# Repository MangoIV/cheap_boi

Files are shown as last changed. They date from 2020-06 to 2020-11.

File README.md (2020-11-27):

# The cheap_boi mechanical keyboard
### The cheap_boi is going to be a new custom mechanical keyboard with a low pricetag
## TL;DR
- WIP, PCB v0.2 has been tested and confirmed working 
- cheap, ortholinear keyboard with  OLED-Display and RGB underglow
- Gerbers added, print on own risk
- [BOM](http://htmlpreview.github.io/?https://github.com/MangoIV/cheap_boi/bom/ibom.html)
## Render of front side
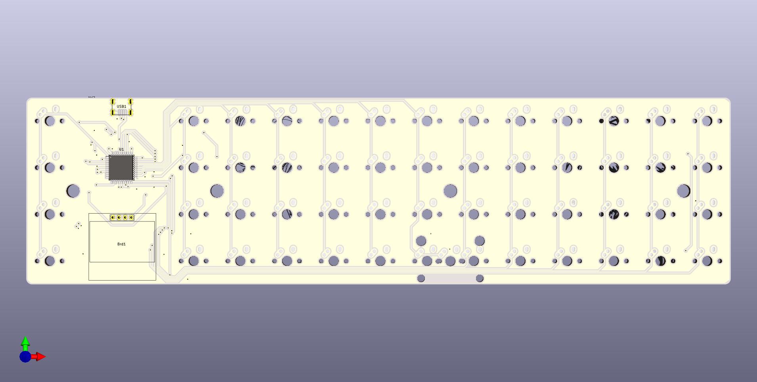
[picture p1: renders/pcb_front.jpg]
render of front side

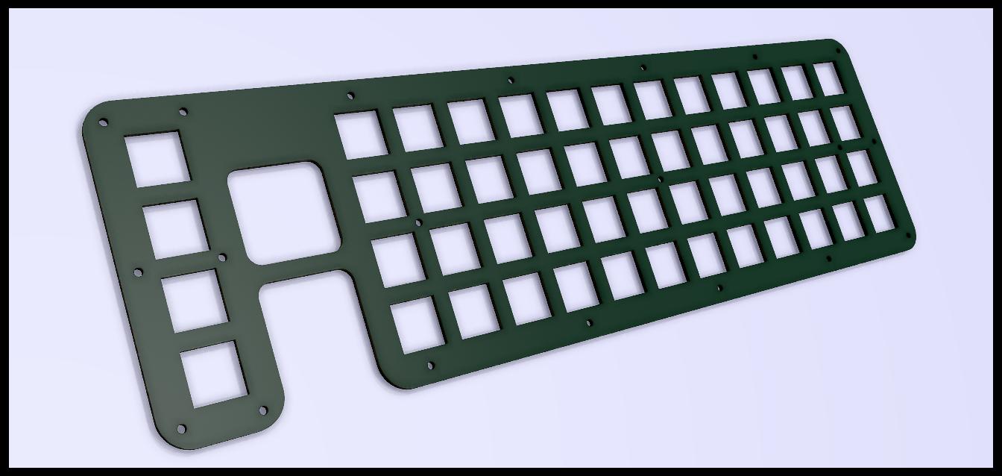
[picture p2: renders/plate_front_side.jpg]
render of front side render of the plate

## Features
### implemented
- microcontroller ATmega32u4
- ortholinear layout similar to the planck
- 4 individual function keys 
- underglow LEDs using WS2812B
- OLED display using SSD1306
- FR4 Bottom- and Switchplate with windows to see microcontroller and OLED
- have a look at the folder "renders" to see renders of the PCB and plates
- a working firmware exists on my fork of the qmk_firmware on the branch cheap_boi
- acrylic case has been made and is confirmed working 
- easier crystal footprint since v0.2
### planned
- alps/mx hybrid switch cutouts on the top plate
- add some nice silkscreen art on PCB and top plate 
### in the future
- change the design to arm, won't come that quickly though 
### current status concerning prototype
- PCBs and parts have arrived and been tested
- the second Prototype has been built and is fully working 
### problems of the current design
- the fit of the acrylic top plate wit the oled is very tight. this results in the need of filing of some materials off the corner of the oleds, this isn't much work tho and doesn't change the functionality of the oled

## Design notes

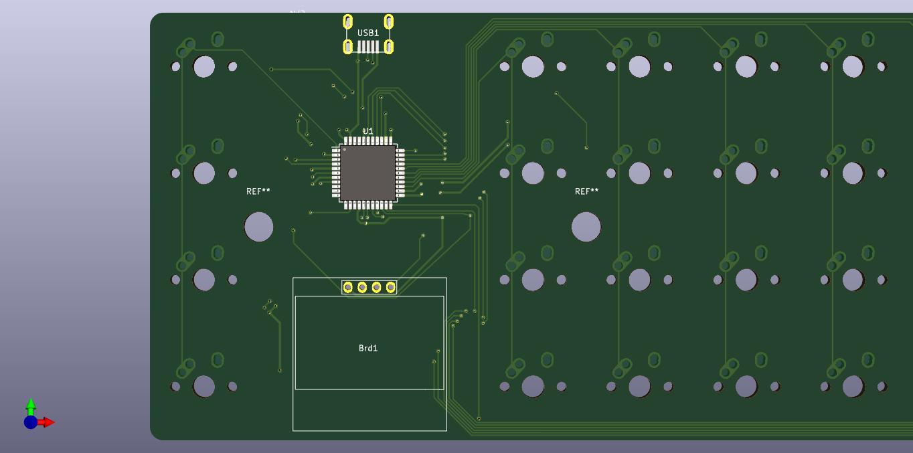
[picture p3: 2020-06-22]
renders/pcb_MCU_area.jpg

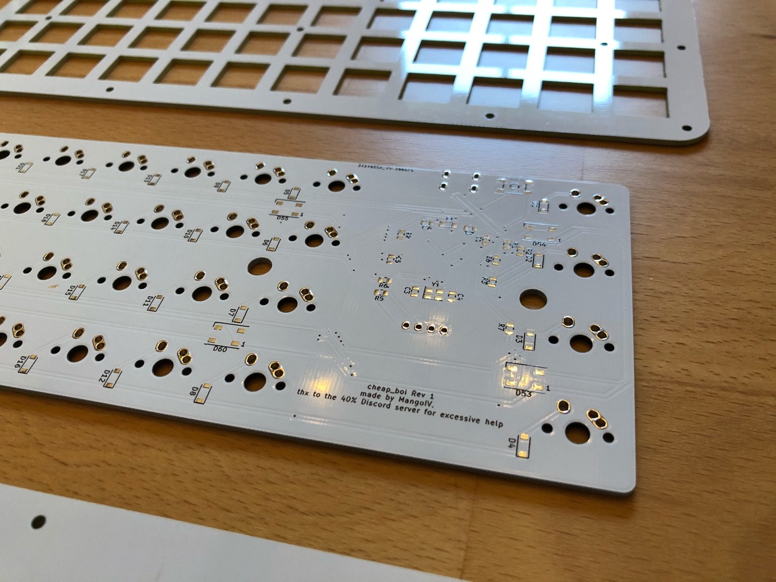
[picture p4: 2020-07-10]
pictures/pcb_back_closeup.jpeg

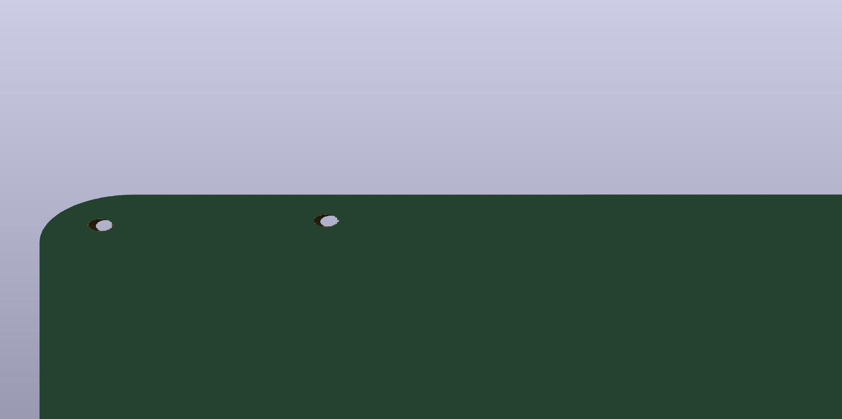
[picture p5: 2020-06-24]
renders/bottom_plate.jpg

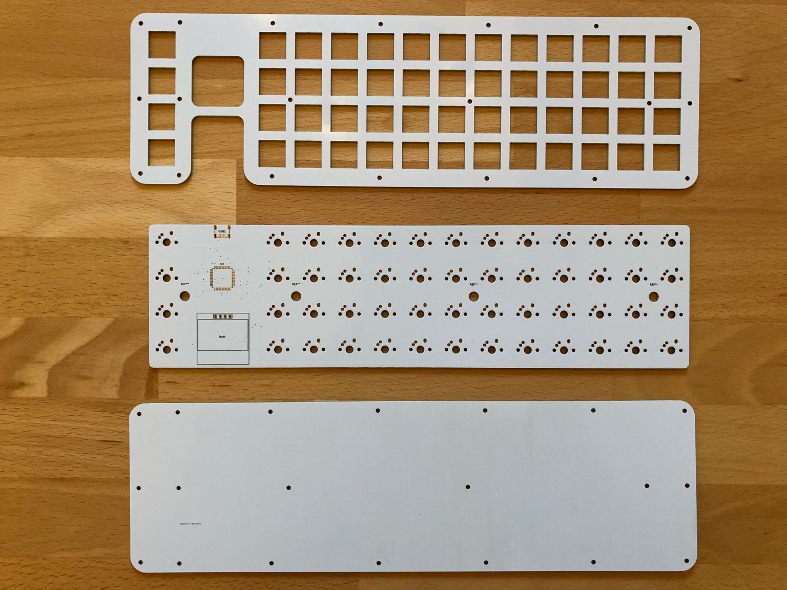
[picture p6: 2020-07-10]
pictures/plate_pcb_bottom.jpeg

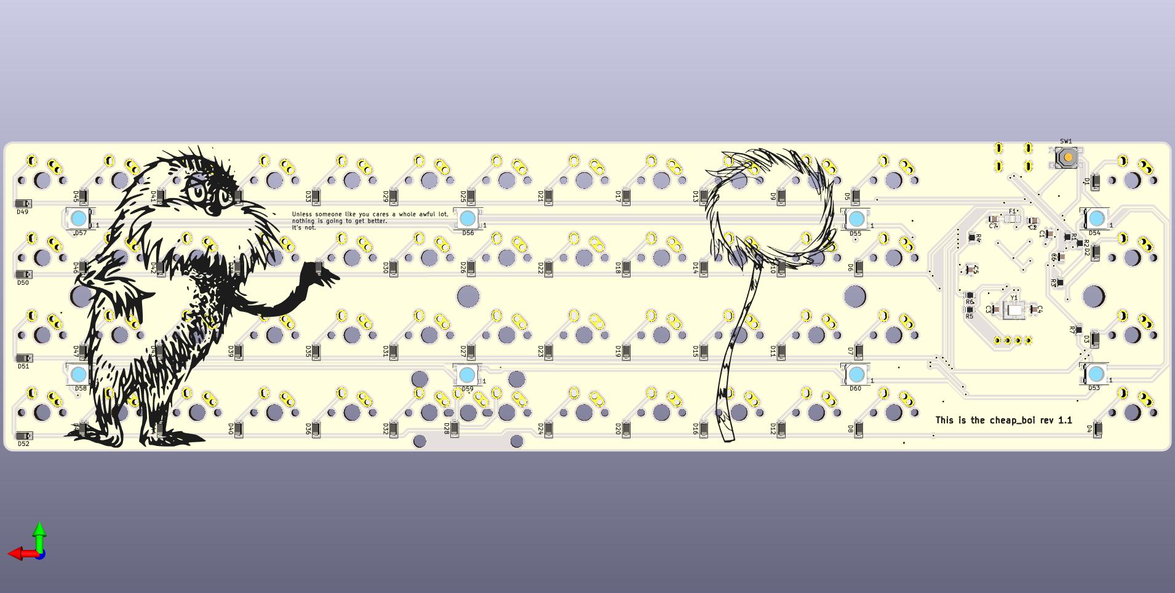
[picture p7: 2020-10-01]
renders/pcb_back.jpg

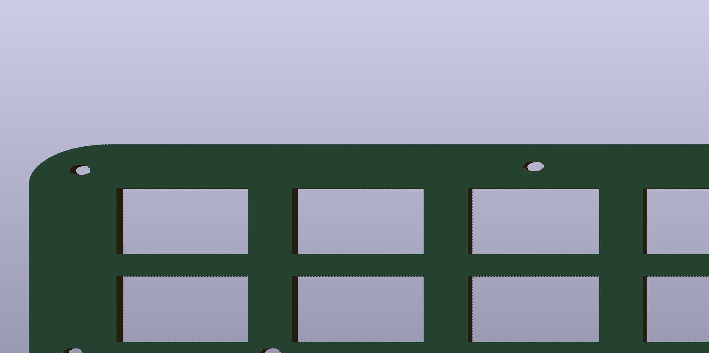
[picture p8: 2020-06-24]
renders/plate_back.jpg

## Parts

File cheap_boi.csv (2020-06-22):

Id | Designator | Package | Quantity | Designation | Supplier and ref
1 | MX0C1,MX15,MX3C1,MX3B1,MX3A1,MX2C1,MX2B1,MX2A1,MX1C1,MX1B1,MX1A1,MX0B1,MX0A1,MX39,MX38,MX37,MX36,MX35,MX34,MX33,MX32,MX31,MX30,MX29,MX28,MX27,MX26,MX25,MX24,MX23,MX22,MX21,MX20,MX19,MX18,MX17,MX16,MX14,MX13,MX12,MX11,MX10,MX9,MX8,MX7,MX6,MX5,MX4,MX3,MX2,MX1,MX0 | MX-1U-NoLED | 52 | MX-NoLED
2 | D1,D52,D51,D50,D49,D48,D47,D46,D45,D44,D43,D42,D41,D40,D39,D38,D37,D36,D35,D34,D33,D32,D31,D30,D29,D28,D27,D26,D25,D24,D23,D22,D21,D20,D19,D18,D17,D16,D15,D14,D13,D12,D11,D10,D9,D8,D7,D6,D5,D4,D3,D2 | D_SOD-123 | 52 | D_Small
3 | D54,D60,D59,D58,D57,D56,D55,D53 | LED_WS2812B_PLCC4_5.0x5.0mm_P3.2mm | 8 | WS2812B
4 | R7 | R_0805_2012Metric | 1 | 500
5 | R6,R5 | R_0805_2012Metric | 2 | 4.7k
6 | R3,R4 | R_0805_2012Metric | 2 | 10k
7 | REF**,REF**,REF**,REF** | MountingHole_5.3mm_M5 | 4 | MountingHole_5.3mm_M5
8 | F1 | Fuse_1206_3216Metric | 1 | Polyfuse_Small
9 | Brd1 | 128x64OLED | 1 | SSD1306
10 | Y1 | Crystal_SMD_3225-4Pin_3.2x2.5mm | 1 | 16MHz
11 | USB1 | Molex-0548190589 | 1 | Molex-0548190589
12 | U1 | TQFP-44_10x10mm_P0.8mm | 1 | ATmega32U4-AU
13 | SW1 | SKQG-1155865 | 1 | SW_Push
14 | R2,R1 | R_0805_2012Metric | 2 | 22
15 | C7 | C_0805_2012Metric | 1 | 10uF
16 | C6 | C_0805_2012Metric | 1 | 1uF
17 | C5,C2,C1 | C_0805_2012Metric | 3 | 0.1uF
18 | C4,C3 | C_0805_2012Metric | 2 | 22pF

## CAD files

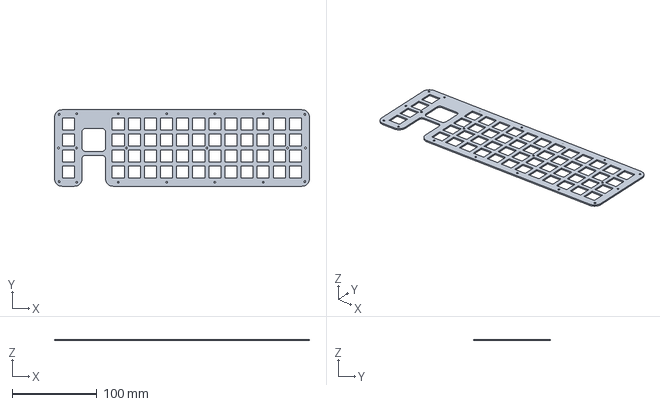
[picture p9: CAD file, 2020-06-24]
step_files/plate.step
301.6 x 90.5 x 1.60 mm

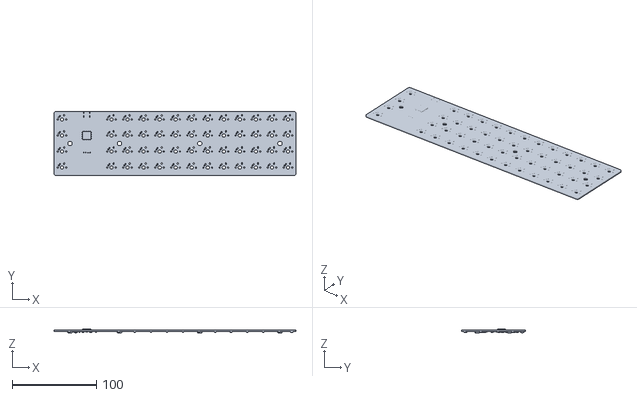
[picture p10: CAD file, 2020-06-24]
stl_files/pcb.stl
287.3 x 76.2 x 4.40

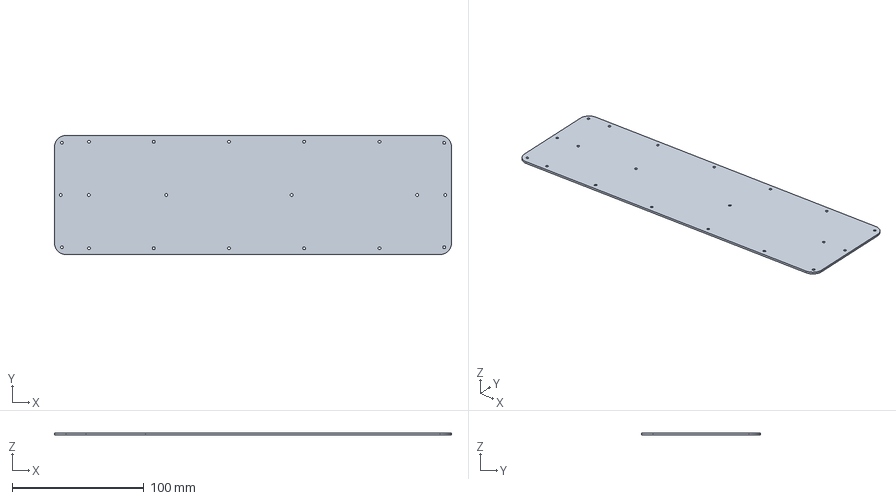
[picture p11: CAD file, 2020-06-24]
step_files/bottom_plate.step
301.6 x 90.5 x 1.60 mm

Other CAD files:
stl_files/bottom_plate.stl
stl_files/plate.stl

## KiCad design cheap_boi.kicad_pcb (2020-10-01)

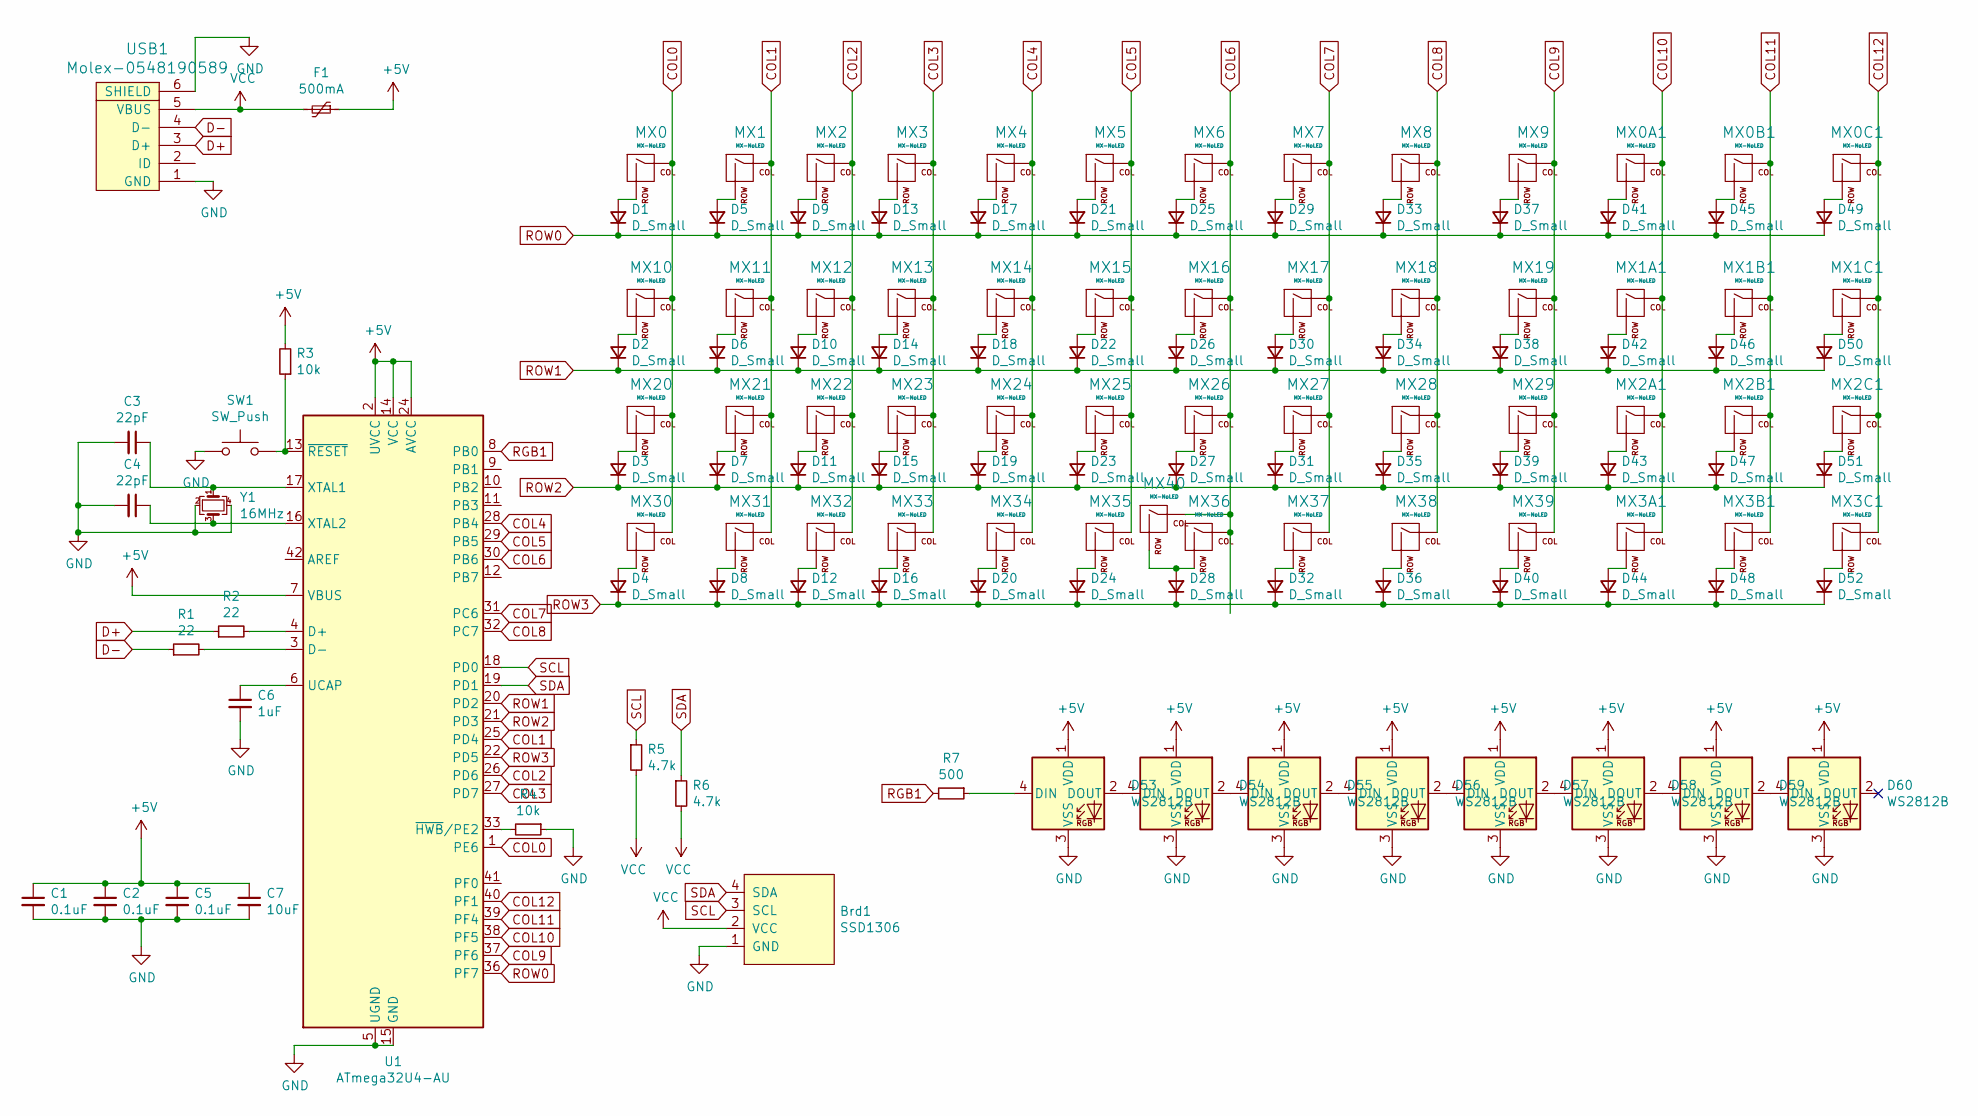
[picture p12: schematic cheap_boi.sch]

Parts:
Brd1: SSD1306; 128x64OLED
C1, C2, C5: 0.1uF; C_0805_2012Metric
C3, C4: 22pF; C_0805_2012Metric
C6: 1uF; C_0805_2012Metric
C7: 10uF; C_0805_2012Metric
D1, D2, D3, D4, D5, D6, D7, D8, D9, D10, D11, D12, D13, D14, D15, D16, D17, D18, D19, D20, D21, D22, D23, D24, D25, D26, D27, D28, D29, D30, D31, D32, D33, D34, D35, D36, D37, D38, D39, D40, D41, D42, D43, D44, D45, D46, D47, D48, D49, D50, D51, D52: D_Small; D_SOD-123
D53, D54, D55, D56, D57, D58, D59, D60: WS2812B; LED_WS2812B_PLCC4_5.0x5.0mm_P3.2mm
F1: 500mA; Fuse_1206_3216Metric
MX0, MX0A1, MX0B1, MX0C1, MX1, MX1A1, MX1B1, MX1C1, MX2, MX2A1, MX2B1, MX2C1, MX3, MX3A1, MX3B1, MX3C1, MX4, MX5, MX6, MX7, MX8, MX9, MX10, MX11, MX12, MX13, MX14, MX15, MX16, MX17, MX18, MX19, MX20, MX21, MX22, MX23, MX24, MX25, MX26, MX27, MX28, MX29, MX30, MX31, MX32, MX33, MX34, MX35, MX36, MX37, MX38, MX39: MX-NoLED; MX-1U-NoLED
MX40: MX-NoLED; MX-2U-ReversedStabilizers-NoLED
R1, R2: 22; R_0805_2012Metric
R3, R4: 10k; R_0805_2012Metric
R5, R6: 4.7k; R_0805_2012Metric
R7: 500; R_0805_2012Metric
SW1: SW_Push; SKQG-1155865
U1: ATmega32U4-AU; TQFP-44_10x10mm_P0.8mm
USB1: Molex-0548190589
Y1: 16MHz; Crystal_SMD_3225-4Pin_3.2x2.5mm_HandSoldering

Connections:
+5V: C1.1, C2.1, C5.1, C7.1, D53.1 (VDD), D54.1 (VDD), D55.1 (VDD), D56.1 (VDD), D57.1 (VDD), D58.1 (VDD), D59.1 (VDD), D60.1 (VDD), F1.1, R3.2, U1.2 (UVCC), U1.7 (VBUS), U1.14 (VCC), U1.24 (AVCC), U1.34 (VCC), U1.44 (AVCC)
COL0: MX0.1 (COL), MX10.1 (COL), MX20.1 (COL), MX30.1 (COL), U1.1 (PE6)
COL1: MX1.1 (COL), MX11.1 (COL), MX21.1 (COL), MX31.1 (COL), U1.25 (PD4)
COL2: MX2.1 (COL), MX12.1 (COL), MX22.1 (COL), MX32.1 (COL), U1.26 (PD6)
COL3: MX3.1 (COL), MX13.1 (COL), MX23.1 (COL), MX33.1 (COL), U1.27 (PD7)
COL4: MX4.1 (COL), MX14.1 (COL), MX24.1 (COL), MX34.1 (COL), U1.28 (PB4)
COL5: MX5.1 (COL), MX15.1 (COL), MX25.1 (COL), MX35.1 (COL), U1.29 (PB5)
COL6: MX6.1 (COL), MX16.1 (COL), MX26.1 (COL), MX36.1 (COL), MX40.1 (COL), U1.30 (PB6)
COL7: MX7.1 (COL), MX17.1 (COL), MX27.1 (COL), MX37.1 (COL), U1.31 (PC6)
COL8: MX8.1 (COL), MX18.1 (COL), MX28.1 (COL), MX38.1 (COL), U1.32 (PC7)
COL9: MX9.1 (COL), MX19.1 (COL), MX29.1 (COL), MX39.1 (COL), U1.37 (PF6)
COL10: MX0A1.1 (COL), MX1A1.1 (COL), MX2A1.1 (COL), MX3A1.1 (COL), U1.38 (PF5)
COL11: MX0B1.1 (COL), MX1B1.1 (COL), MX2B1.1 (COL), MX3B1.1 (COL), U1.39 (PF4)
COL12: MX0C1.1 (COL), MX1C1.1 (COL), MX2C1.1 (COL), MX3C1.1 (COL), U1.40 (PF1)
D+: R2.1, USB1.3 (D+)
D-: R1.1, USB1.4 (D-)
GND: Brd1.1 (GND), C1.2, C2.2, C3.2, C4.2, C5.2, C6.2, C7.2, D53.3 (VSS), D54.3 (VSS), D55.3 (VSS), D56.3 (VSS), D57.3 (VSS), D58.3 (VSS), D59.3 (VSS), D60.3 (VSS), R4.1, SW1.1, U1.5 (UGND), U1.15 (GND), U1.23 (GND), U1.35 (GND), U1.43 (GND), USB1.1 (GND), USB1.6 (SHIELD), Y1.2, Y1.4
unnamed: C3.1, U1.17 (XTAL1), Y1.1
unnamed: C4.1, U1.16 (XTAL2), Y1.3
unnamed: C6.1, U1.6 (UCAP)
unnamed: D1.2 (A), MX0.2 (ROW)
unnamed: D2.2 (A), MX10.2 (ROW)
unnamed: D3.2 (A), MX20.2 (ROW)
unnamed: D4.2 (A), MX30.2 (ROW)
unnamed: D5.2 (A), MX1.2 (ROW)
unnamed: D6.2 (A), MX11.2 (ROW)
unnamed: D7.2 (A), MX21.2 (ROW)
unnamed: D8.2 (A), MX31.2 (ROW)
unnamed: D9.2 (A), MX2.2 (ROW)
unnamed: D10.2 (A), MX12.2 (ROW)
unnamed: D11.2 (A), MX22.2 (ROW)
unnamed: D12.2 (A), MX32.2 (ROW)
unnamed: D13.2 (A), MX3.2 (ROW)
unnamed: D14.2 (A), MX13.2 (ROW)
unnamed: D15.2 (A), MX23.2 (ROW)
unnamed: D16.2 (A), MX33.2 (ROW)
unnamed: D17.2 (A), MX4.2 (ROW)
unnamed: D18.2 (A), MX14.2 (ROW)
unnamed: D19.2 (A), MX24.2 (ROW)
unnamed: D20.2 (A), MX34.2 (ROW)
unnamed: D21.2 (A), MX5.2 (ROW)
unnamed: D22.2 (A), MX15.2 (ROW)
unnamed: D23.2 (A), MX25.2 (ROW)
unnamed: D24.2 (A), MX35.2 (ROW)
unnamed: D25.2 (A), MX6.2 (ROW)
unnamed: D26.2 (A), MX16.2 (ROW)
unnamed: D27.2 (A), MX26.2 (ROW)
unnamed: D28.2 (A), MX36.2 (ROW), MX40.2 (ROW)
unnamed: D29.2 (A), MX7.2 (ROW)
unnamed: D30.2 (A), MX17.2 (ROW)
unnamed: D31.2 (A), MX27.2 (ROW)
unnamed: D32.2 (A), MX37.2 (ROW)
unnamed: D33.2 (A), MX8.2 (ROW)
unnamed: D34.2 (A), MX18.2 (ROW)
unnamed: D35.2 (A), MX28.2 (ROW)
unnamed: D36.2 (A), MX38.2 (ROW)
unnamed: D37.2 (A), MX9.2 (ROW)
unnamed: D38.2 (A), MX19.2 (ROW)
unnamed: D39.2 (A), MX29.2 (ROW)
unnamed: D40.2 (A), MX39.2 (ROW)
unnamed: D41.2 (A), MX0A1.2 (ROW)
unnamed: D42.2 (A), MX1A1.2 (ROW)
unnamed: D43.2 (A), MX2A1.2 (ROW)
unnamed: D44.2 (A), MX3A1.2 (ROW)
unnamed: D45.2 (A), MX0B1.2 (ROW)
unnamed: D46.2 (A), MX1B1.2 (ROW)
unnamed: D47.2 (A), MX2B1.2 (ROW)
unnamed: D48.2 (A), MX3B1.2 (ROW)
unnamed: D49.2 (A), MX0C1.2 (ROW)
unnamed: D50.2 (A), MX1C1.2 (ROW)
unnamed: D51.2 (A), MX2C1.2 (ROW)
unnamed: D52.2 (A), MX3C1.2 (ROW)
unnamed: D53.2 (DOUT), D54.4 (DIN)
unnamed: D53.4 (DIN), R7.1
unnamed: D54.2 (DOUT), D55.4 (DIN)
unnamed: D55.2 (DOUT), D56.4 (DIN)
unnamed: D56.2 (DOUT), D57.4 (DIN)
unnamed: D57.2 (DOUT), D58.4 (DIN)
unnamed: D58.2 (DOUT), D59.4 (DIN)
unnamed: D59.2 (DOUT), D60.4 (DIN)
unnamed: R1.2, U1.3 (D-)
unnamed: R2.2, U1.4 (D+)
unnamed: R3.1, SW1.2, U1.13 (~RESET)
unnamed: R4.2, U1.33 (~HWB~/PE2)
RGB1: R7.2, U1.8 (PB0)
ROW0: D1.1 (K), D5.1 (K), D9.1 (K), D13.1 (K), D17.1 (K), D21.1 (K), D25.1 (K), D29.1 (K), D33.1 (K), D37.1 (K), D41.1 (K), D45.1 (K), D49.1 (K), U1.36 (PF7)
ROW1: D2.1 (K), D6.1 (K), D10.1 (K), D14.1 (K), D18.1 (K), D22.1 (K), D26.1 (K), D30.1 (K), D34.1 (K), D38.1 (K), D42.1 (K), D46.1 (K), D50.1 (K), U1.20 (PD2)
ROW2: D3.1 (K), D7.1 (K), D11.1 (K), D15.1 (K), D19.1 (K), D23.1 (K), D27.1 (K), D31.1 (K), D35.1 (K), D39.1 (K), D43.1 (K), D47.1 (K), D51.1 (K), U1.21 (PD3)
ROW3: D4.1 (K), D8.1 (K), D12.1 (K), D16.1 (K), D20.1 (K), D24.1 (K), D28.1 (K), D32.1 (K), D36.1 (K), D40.1 (K), D44.1 (K), D48.1 (K), D52.1 (K), U1.22 (PD5)
SCL: Brd1.3 (SCL), R5.1, U1.18 (PD0)
SDA: Brd1.4 (SDA), R6.1, U1.19 (PD1)
VCC: Brd1.2 (VCC), F1.2, R5.2, R6.2, USB1.5 (VBUS)

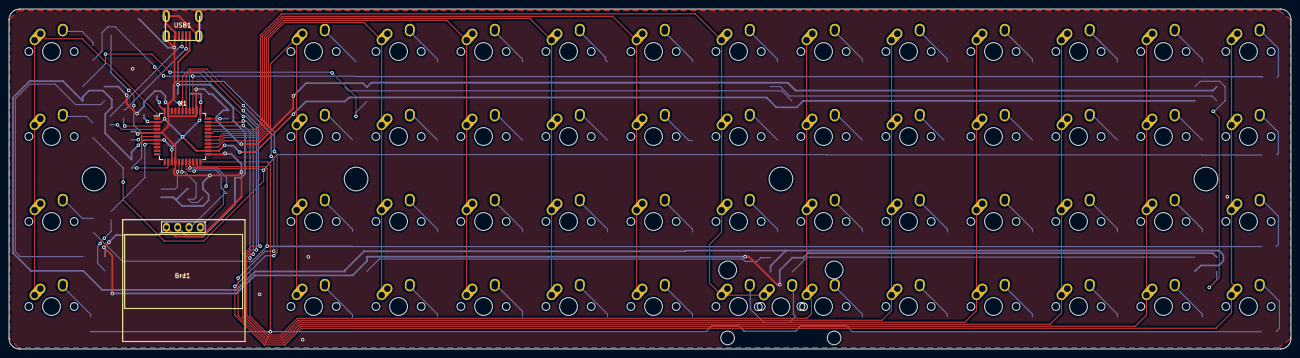
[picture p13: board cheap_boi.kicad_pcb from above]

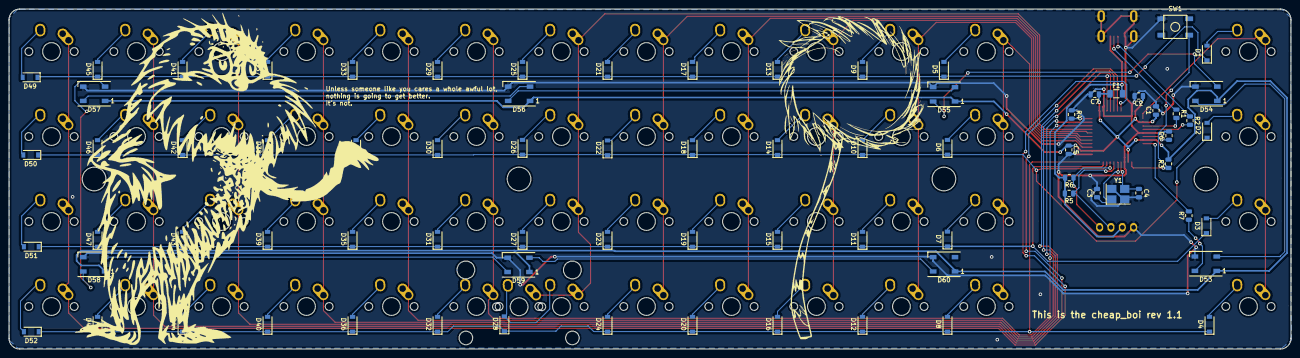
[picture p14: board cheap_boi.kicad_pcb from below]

Board: 2 copper layers, 287.3 x 76.2 mm, 137 parts (77 on the bottom side), 92 nets.

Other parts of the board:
 : MountingHole_5.3mm_M5
 #2,  #3,  #4: MountingHole_5.3mm_M5

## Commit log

2020-06-20 create kicad project
    [cheap_boi.kicad_pcb, cheap_boi.sch]
2020-06-20 update footprints
2020-06-20 added schematic
2020-06-20 assigned footprints for all components
    [cheap_boi.sch]
2020-06-20 everything added besides cutout and usb-connector
    [cheap_boi.kicad_pcb]
2020-06-20 last commit of the day
    [cheap_boi.kicad_pcb]
2020-06-21 add SSD1306-128x64 submodule
    [cheap_boi.kicad_pcb]
2020-06-21 added RGB breakout and ordered parts in symmetrically
    [cheap_boi.kicad_pcb, cheap_boi.sch]
2020-06-21 added connection of rows and cols to microcontroller
    [cheap_boi.kicad_pcb, cheap_boi.sch]
2020-06-21 tracing is done, PCB should be functional
    [cheap_boi.kicad_pcb, cheap_boi.sch]
2020-06-22 silkscreen text, GND fill, error checking
    [cheap_boi.kicad_pcb]
2020-06-22 added RGB underglow, removed 3 pin breakout for RGB underglow
    [cheap_boi.kicad_pcb, cheap_boi.sch]
2020-06-22 add png render front side of pcb
2020-06-22 added evenly distributed groundfill
    [cheap_boi.kicad_pcb]
2020-06-22 revised traces that where 90deg and smaller
    [cheap_boi.kicad_pcb]
2020-06-22 added bom, changed readme
    [cheap_boi.csv]
2020-06-22 add Gerbers + gerber zip
    [cheap_boi-B_Cu.gbl, cheap_boi-B_Cu.gbr, cheap_boi-B_Mask.gbr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]
2020-06-22 imagine a good commit message, don't have time
    [cheap_boi.kicad_pcb, plate.kicad_pcb]
2020-06-22 added switch plate
    [plate.kicad_pcb]
2020-06-22 finished plate, added renders of plate
    [plate.kicad_pcb]
2020-06-23 bottom plate finished, render added
    [bottom_plate.kicad_pcb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]
2020-06-24 added new gerbers
    [bottom_plate-B_Cu.gbl, bottom_plate-B_Mask.gbs, bottom_plate-B_SilkS.gbo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]
2020-06-24 changed folders
    [bottom_plate-B_Cu.gbl, bottom_plate-B_Mask.gbs, bottom_plate-B_SilkS.gbo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]
2020-06-24 clean up
    [bottom_plate.step, bottom_plate.stl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]
2020-06-30 changed render plate front
2020-10-01 we are now on rev 1.1, pcbs soon to be tested
    [bottom_plate-B_Cu.gbl, bottom_plate-B_Mask.gbs, bottom_plate-B_SilkS.gbo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]
2020-10-01 added shots of the pcb renderer in kicad
2020-10-12 updated the plate to work with 2u and stabs
    [plate.kicad_pcb]
